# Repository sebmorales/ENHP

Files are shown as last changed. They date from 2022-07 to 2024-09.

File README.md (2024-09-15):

# Networked Hardware- Getting Started

Woo! You got your board on the mail, or maybe we gave it to you in person, now, what is it? What is it for?
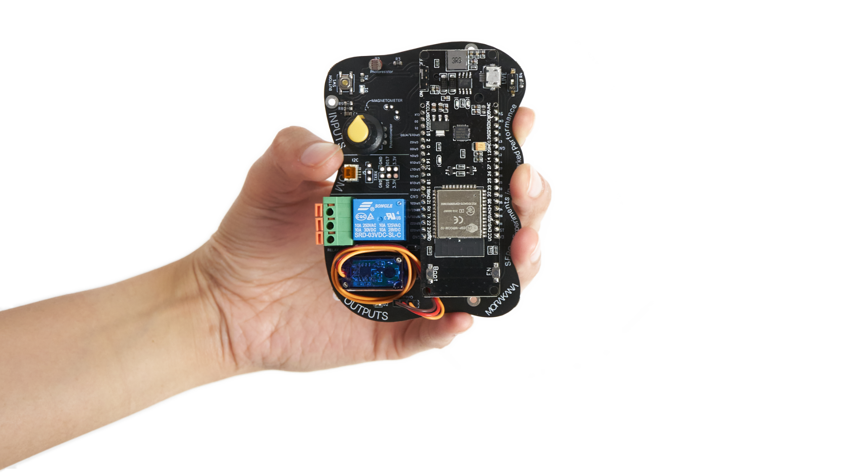
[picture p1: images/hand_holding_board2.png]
Networked Hardware 2.0


This board is based on a ESP32 microcontroller, but it also has some other components to help us get started connecting the digital world and our tangible one. We will go more in depth during class, but for now, here is a quick manual to get you going. 

By default, the board is already pre-programmed, so you don’t have to worry about that. But if you want to make changes, you are more than welcome to do so. We will soon update this same doc to share the code and schematics.

*Note: The board in a bit of an experimental stage and we are still trying to figure things out, so please share any feedback and bugs as you find them :)*

Each board has a unique name (written by hand on the back of the board). Let’s get the boards connected and start sharing light data!

If you go to the webpage [https://hardwaremovement.com](https://hardwaremovement.com) you will see a grid of boxes, each with a name. At the time I took this image, there were only three boards on there, hopefully by now there are many more. As new boards connect, the grid starts getting updated with each boards' last photoresistor reading. 
    
        

This website is only collecting light information, and since other people will likely connect at different times, feel free to come back and see how the collaborative page is changing over time. Feel free to place the board anywhere indoors and see how that impacts the page. 

## Let’s connect!

### How to connect the board to wifi [video]

[https://vimeo.com/725318091](https://vimeo.com/725318091)

### How to connect the board to wifi step by step

1. Turn on the switch on the ESP32 board. 
    1. You will hear a click (that's the relay acting as a small audio cue)
    2. You will see the board blink about 1x a second, this means that the board is attempting to connect to a wifi network. But because you just got the board it will most likely not be able to connect.
        
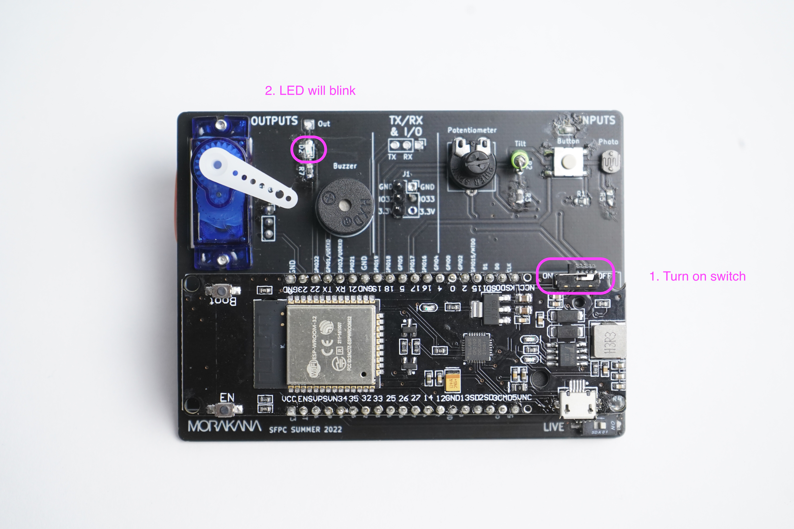
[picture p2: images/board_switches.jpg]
            
2. If after 15 seconds it wasn’t able to connect:
    1. The board will beep again
    2. The LED will start blinking at a faster pace (2x second)
    3. It will then make its own wifi network. You can connect to it to share your wifi credentials. You can do this either though your phone or computer’s wifi settings. 
    
    The name of the network will be *ExperimentHardPerf_[random numbers]*

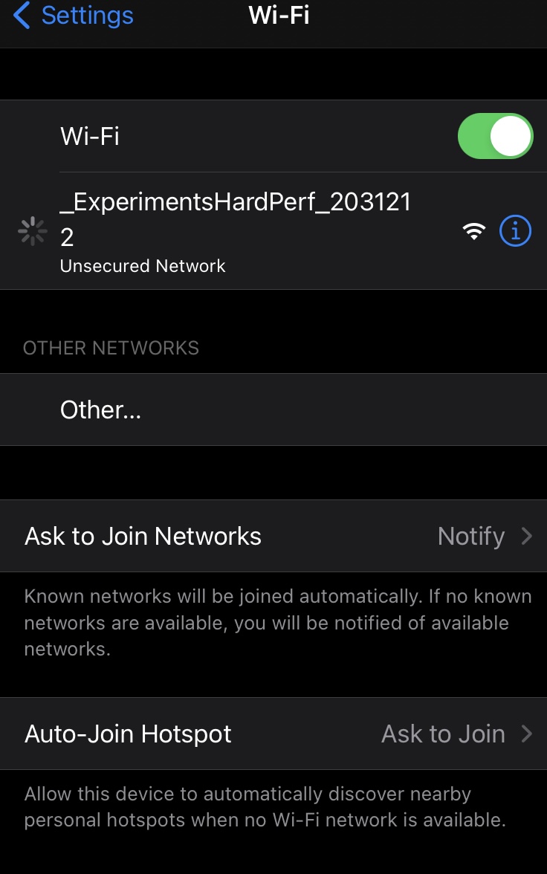
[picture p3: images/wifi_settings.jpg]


1. After 5-10 seconds a login page (captive portal) will show up on your device. 
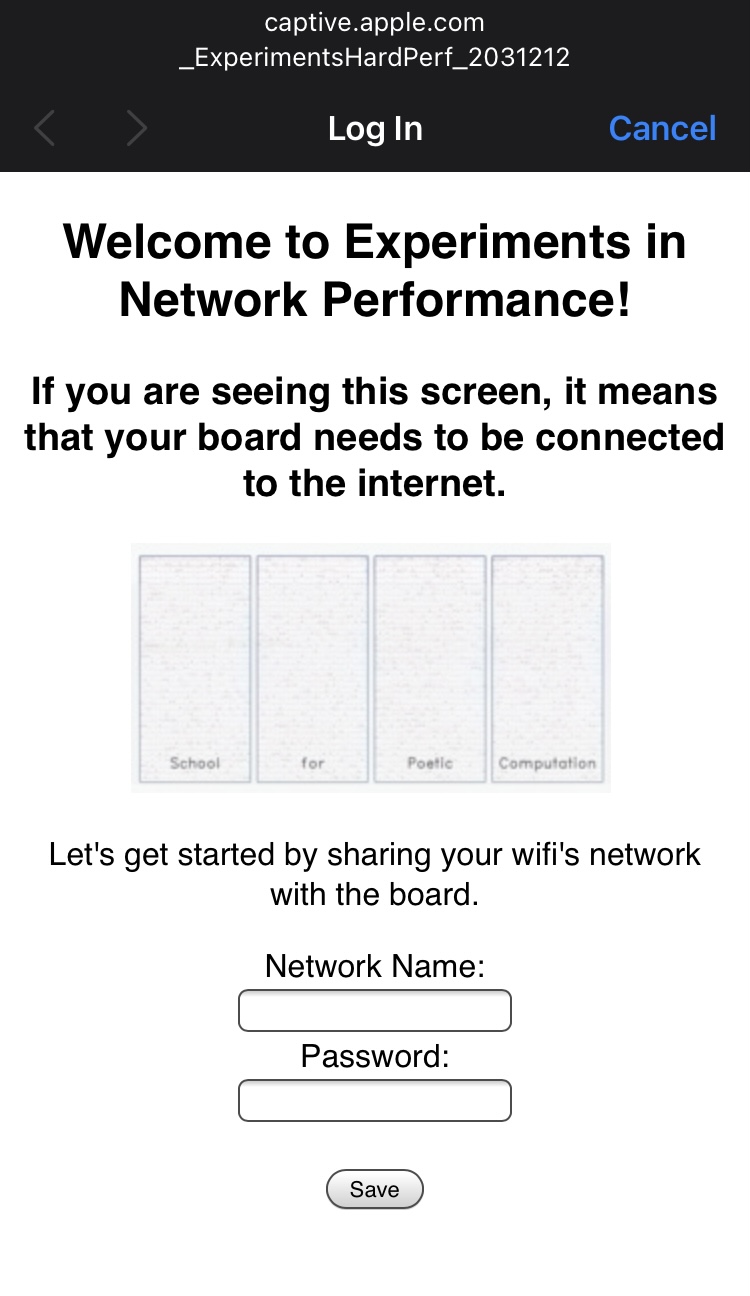
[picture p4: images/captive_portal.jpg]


Note: watch out for upper/lower case

1. Enter your wifi info then click save (Note: watch out for upper/lower case)
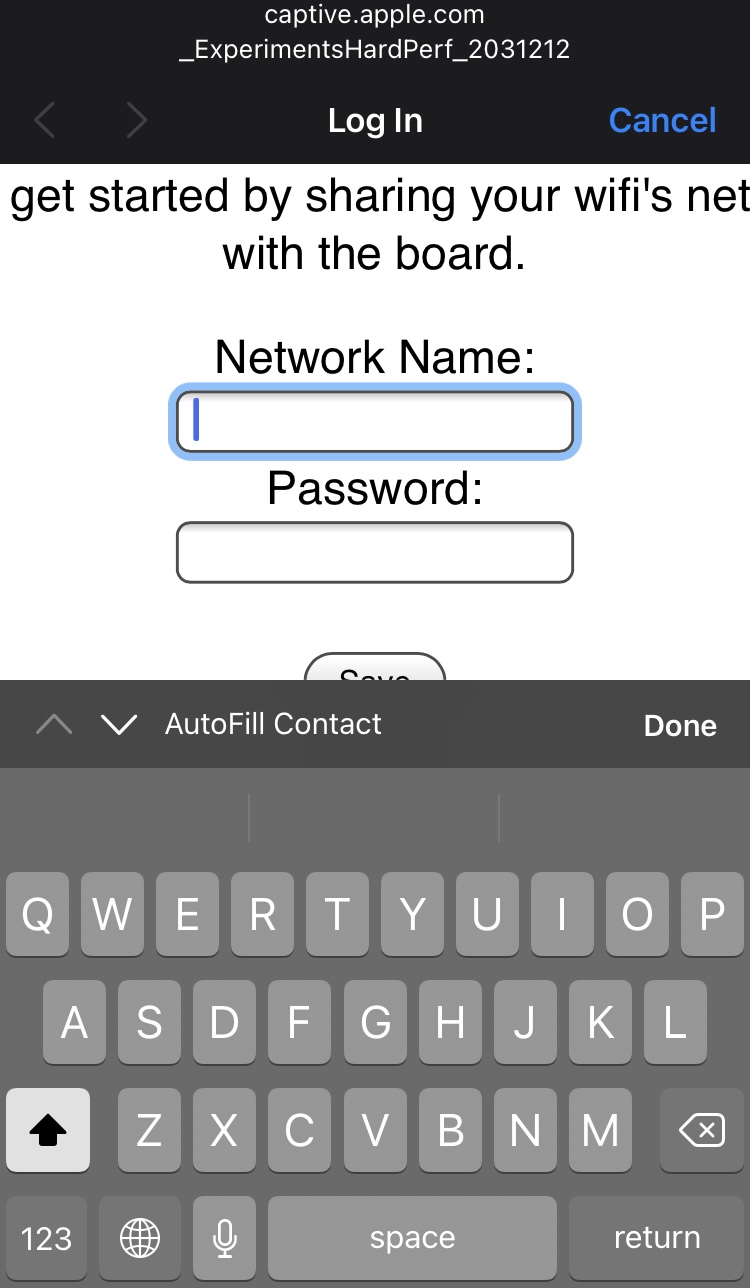
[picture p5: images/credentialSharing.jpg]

Note: watch out for upper/lower case

1. Once you click save, the board will attempt to connect to your network. It will also save your network credentials to it’s internal memory, so you don’t have to add them again (unless you change them). You can now press cancel>use other network, and connect to your regular wifi.

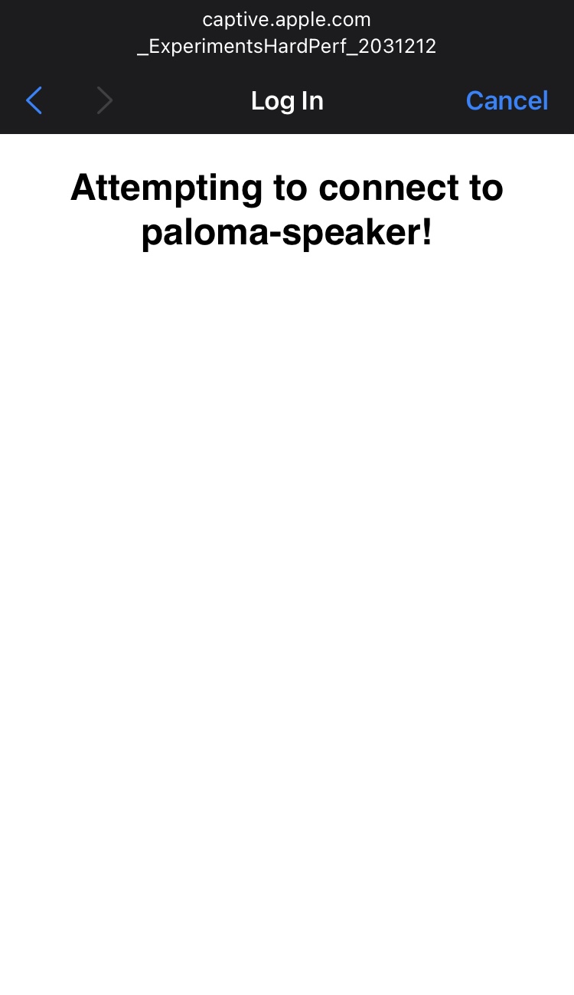
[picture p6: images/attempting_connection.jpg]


1. If the connection is successful, you will see a quick short flashing LED. Then then you can check the [https://hardwaremovement.com](https://hardwaremovement.com)  website again and see it updating live! The board should then go to sleep and automatically wake up every 20 minutes until it rans out of battery in about a day. If you want, you can charge it again or leave it plugged in. 

### Trouble shooting

- I turn it on but nothing happens, no beep, no flashing led.
    
    Most likely, it’s out of battery, try charging it though the micro USB port
    
- I turn the board on, and it beeps, then it beeps again, and again, and again…
    
    This means that the board is constantly restarting, most likely it’s out of battery, try recharging the battery though it’s Micro USB port
    
- I added my wifi credentials but doesn’t nothing happened.
    
    Try restarting the board by turning it off and on again, the board should attempt to connect and if it still is not able, repeat steps 2-6.
    
    Also, in order to save battery, it will only wait for 1minute before going back to sleep. It could be that it’s taking a bit long to add your wifi credentials.
    
- I was able to connect before now it’s asking for my wifi credentials again
    
    The board only has 15 seconds to successfully connect to wifi, after this it will create it’s own network. Sometimes, these 15 seconds are not enough time connect, no need to add you credentials again, you can restart the board and have it try again. 

---

### Additional info: Getting familiar with the board



The board consists of the micocontroller ([ESP32 dev board with a 18650 battery holder](https://wiki.geekworm.com/index.php/WEMOS_ESP32_Board_with_18650_Battery_Holder)) and a series of inputs and outputs:

### **Inputs:**

- **Photoresistor**- This can be used to sense light
- **Magnetometer**- This is the ([MMC5603NJ](mages/MMC5603NJ.pdf)), a 3 axis magnetic + temperature sensor
- **Potentiometer**- This is a knob can be manually turned
- **Button-** This button has a dual function, to send data while the board is awake, and to wake the board when it is sleeping

### **Outputs:**

- **Relay**- Instead of having a buzzer that could only buzz, we upgraded it to a full size relay, it clicks and it switches! We recomend only using it for DC applications, but if you know what you are doing feel free. 
- **An LED output and pin-** this can be used to see changes or to connect to another board or arduino.
- **A Servo-** this can be used to move things in our physical, it can turn about 180°.

### **COM:**
- **I2C**- This uses a STEMMA QT connector, a popular i2C compatible with many Adafruit and Sparkfun modules.
- **RXTX**- These are ready in case you want to connect to another micrcontroller or anything that can communicate though serial. By default the board runs on a 115200 buadrate and only supports 3.3V.
- **GPIO 17 & 18**- By defualt 17 is set to be a digital input (0-1) and 18 is set as an analog out (0-255).
### Power

- The ESP32 board has a switch to turn it on/off
- It can be charged/programmed using a micro USB cable
- We added a small switch to let you decide if the board should stay connected or if it should connect every 20 minutes and then go to sleep. This will dramatically impact how long the board can run on battery.

## Check out [MORAKANA.COM](https://morakana.com/work/networked-hardware2.0) for more details and examples.

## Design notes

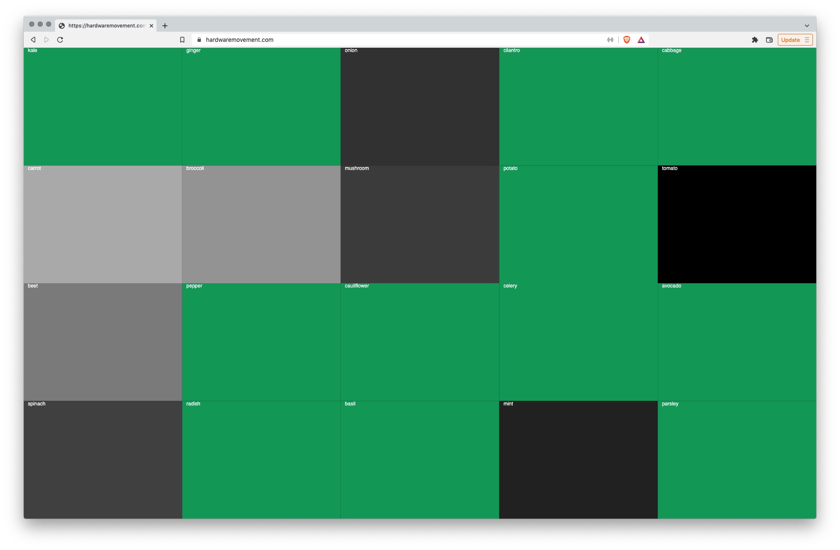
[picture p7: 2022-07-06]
images/hardwaremovement.png

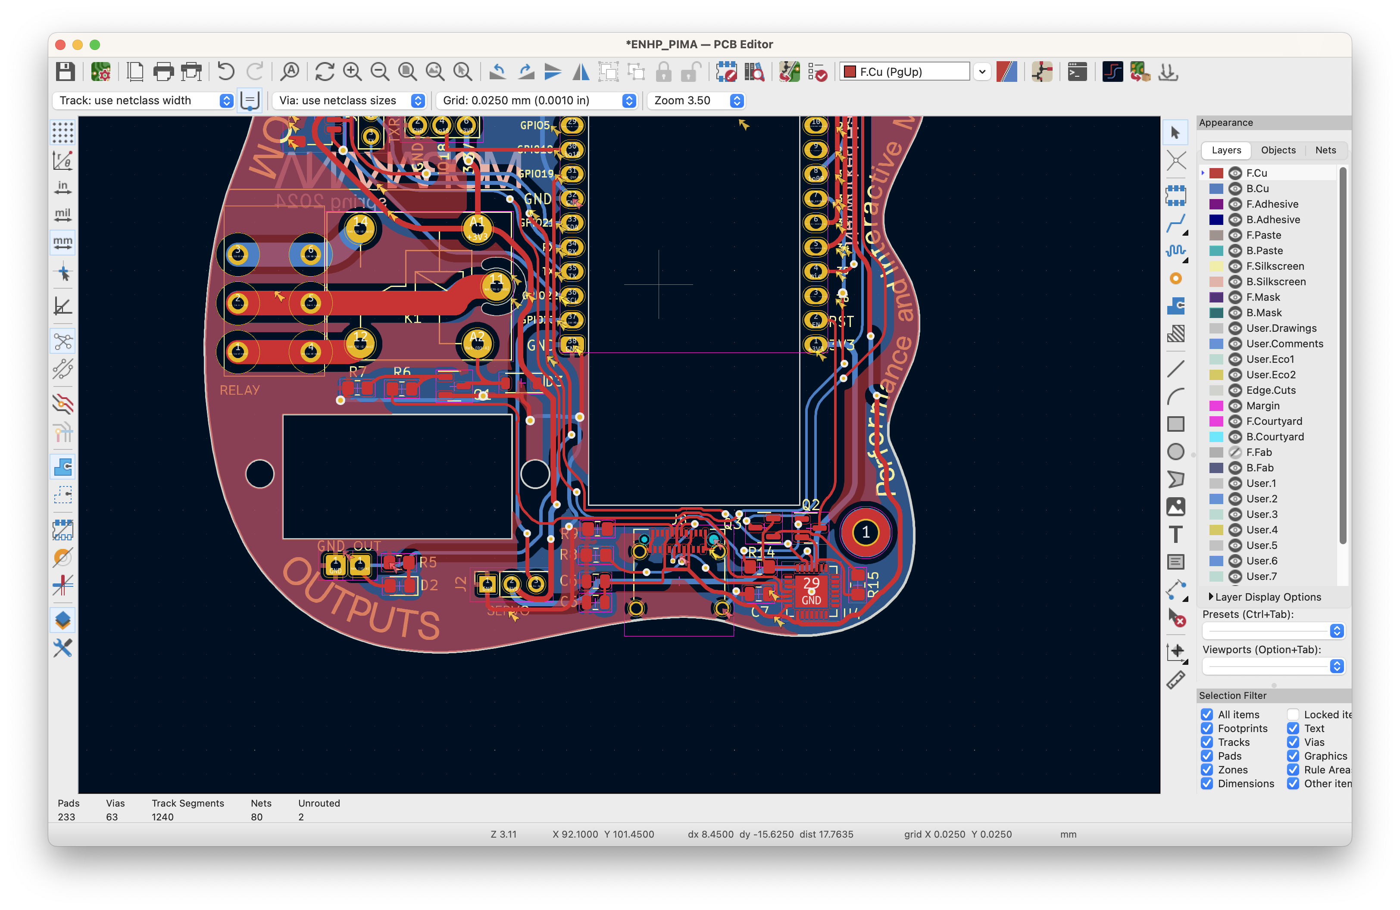
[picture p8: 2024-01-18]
NetworkedHardware_PCB_design/NetworkHardware2.3.png

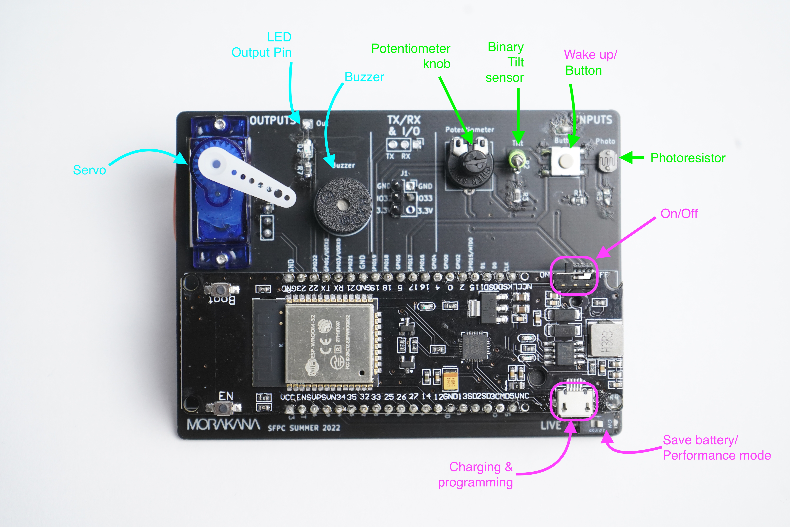
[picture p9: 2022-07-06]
images/boardIO.jpg

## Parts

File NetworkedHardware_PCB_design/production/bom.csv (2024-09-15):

Designator | Footprint | Quantity | Value | LCSC Part #
C1, C4 | 0805 | 2 | 10uF
C2 | 0805 | 1 | 220nF
C3 | 0805 | 1 | 0.1uF
C5 | 0805 | 1 | 1uF
C6, C7 | 0805 | 2 | 100nF
D1, D2 | 0805 | 2 | LED
D3 | D_SOD-123 | 1 | 1N4148W
H1, H4 | MountingHole_2.5mm_Pad_TopBottom | 2 | MountingHole
J1 | PinSocket_2x03_P2.54mm_Vertical | 1 | hookup
J2 | PinSocket_1x03_P2.54mm_Vertical | 1 | SERVO
J3 | PinHeader_1x03_P2.54mm_Vertical | 1 | TXRX
J4 | SolderWire-0.5sqmm_1x01_D0.9mm_OD2.1mm | 1 | OUT0
J5 | JST_SH_SM04B-SRSS-TB_1x04-1MP_P1.00mm_Horizontal | 1 | I2C
J6 | spring_terminal | 1 | ~
J7 | SolderWire-0.5sqmm_1x01_D0.9mm_OD2.1mm | 1 | GND
J8 | USB_C_Receptacle_Amphenol_12401610E4-2A_CircularHoles | 1 | USB_C_Receptacle_USB2.0
K1 | Relay_SPDT_Finder_36.11 | 1 | FINDER-36.11
MIC | S15OT421 | 1 | S15OT421 | C2684419
Q1 | SOT-23 | 1 | MMBT3904
Q2, Q3 | SOT-23 | 2 | BC817
R1 | 0805 | 1 | R220
R10, R11, R14, R15, R3, R7 | 0805 | 6 | 10K
R12, R13 | 0805 | 2 | 2.7K
R2 | R_Axial_DIN0204_L3.6mm_D1.6mm_P2.54mm_Vertical | 1 | Photoresistor
R4 | 0805 | 1 | 1M
R5 | 0805 | 1 | 220
R6 | 0805 | 1 | 1K
R8, R9 | 0805 | 2 | 5.1K
RV5K1 | Potentiometer_Bourns_PTV09A-1_Single_Vertical | 1 | Potentiometer
SW1 | SW_Push_1P1T_NO_CK_KSC7xxJ | 1 | SW_DIP_x01
SW2 | SW_DIP_SPSTx01_Slide_Omron_A6S-110x_W8.9mm_P2.54mm | 1 | SW_DIP_x01
U1 | ESP32-Dev_Batt_18650 | 1 | ESP32-DevKitC
U2 | SOT-23-5 | 1 | MIC5225-3.3YM5 | C512101
U3 | LGA-12_2x2mm_P0.5mm | 1 | LSM303C
U4 | QFN-28-1EP_5x5mm_P0.5mm_EP3.35x3.35mm | 1 | CP2102N-Axx-xQFN28

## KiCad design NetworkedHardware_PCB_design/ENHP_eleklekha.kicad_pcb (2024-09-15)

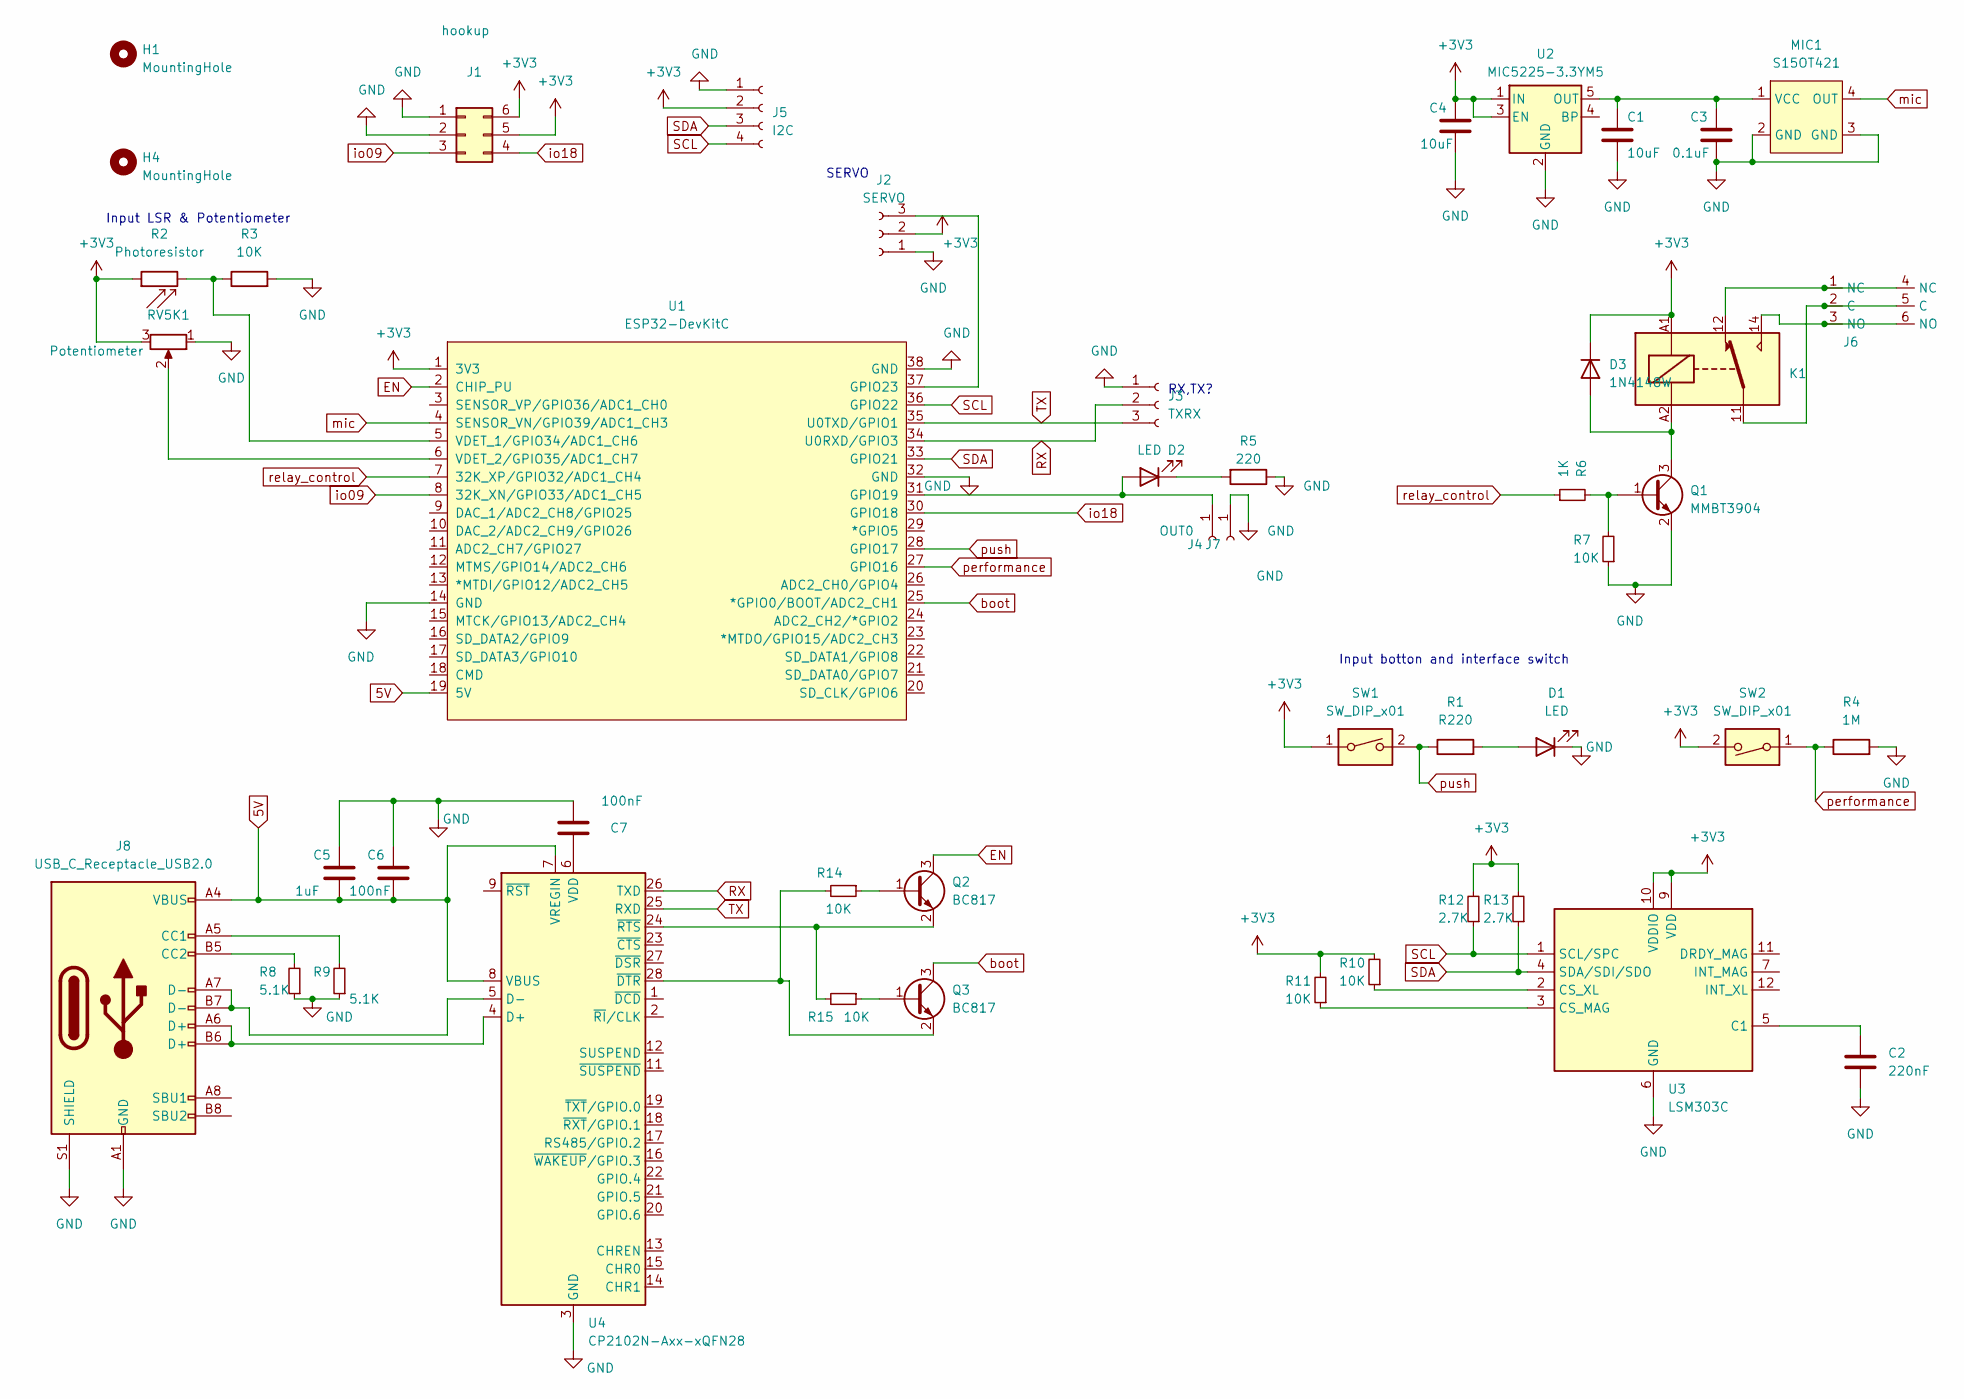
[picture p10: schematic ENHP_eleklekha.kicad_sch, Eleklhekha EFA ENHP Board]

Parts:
C1, C4: 10uF; C_0805_2012Metric
C2: 220nF; C_0805_2012Metric
C3: 0.1uF; C_0805_2012Metric
C5: 1uF; C_0805_2012Metric
C6, C7: 100nF; C_0805_2012Metric
D1, D2: LED; LED_0805_2012Metric_Pad1.15x1.40mm_HandSolder
D3: 1N4148W; D_SOD-123
H1, H4: MountingHole; MountingHole_2.5mm_Pad_TopBottom
J1: hookup; PinSocket_2x03_P2.54mm_Vertical
J2: SERVO; PinSocket_1x03_P2.54mm_Vertical
J3: TXRX; PinHeader_1x03_P2.54mm_Vertical
J4: OUT0; SolderWire-0.5sqmm_1x01_D0.9mm_OD2.1mm
J5: I2C; JST_SH_SM04B-SRSS-TB_1x04-1MP_P1.00mm_Horizontal
J6: spring_terminal
J7: GND; SolderWire-0.5sqmm_1x01_D0.9mm_OD2.1mm
J8: USB_C_Receptacle_USB2.0; USB_C_Receptacle_Amphenol_12401610E4-2A_CircularHoles
K1: FINDER-36.11; Relay_SPDT_Finder_36.11
MIC1: S15OT421; JLC C2684419
Q1: MMBT3904; SOT-23
Q2, Q3: BC817; SOT-23
R1: R220; R_0805_2012Metric_Pad1.20x1.40mm_HandSolder
R2: Photoresistor; R_Axial_DIN0204_L3.6mm_D1.6mm_P2.54mm_Vertical
R3, R7, R10, R11, R14, R15: 10K; R_0805_2012Metric_Pad1.20x1.40mm_HandSolder
R4: 1M; R_0805_2012Metric_Pad1.20x1.40mm_HandSolder
R5: 220; R_0805_2012Metric_Pad1.20x1.40mm_HandSolder
R6: 1K; R_0805_2012Metric_Pad1.20x1.40mm_HandSolder
R8, R9: 5.1K; R_0805_2012Metric_Pad1.20x1.40mm_HandSolder
R12, R13: 2.7K; R_0805_2012Metric_Pad1.20x1.40mm_HandSolder
RV5K1: Potentiometer; Potentiometer_Bourns_PTV09A-1_Single_Vertical
SW1: SW_DIP_x01; SW_Push_1P1T_NO_CK_KSC7xxJ
SW2: SW_DIP_x01; SW_DIP_SPSTx01_Slide_Omron_A6S-110x_W8.9mm_P2.54mm
U1: ESP32-DevKitC; ESP32-Dev_Batt_18650
U2: MIC5225-3.3YM5; SOT-23-5; JLC C512101
U3: LSM303C; LGA-12_2x2mm_P0.5mm
U4: CP2102N-Axx-xQFN28; QFN-28-1EP_5x5mm_P0.5mm_EP3.35x3.35mm

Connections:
5V: C5.2, C6.2, J8.A4 (VBUS), J8.A9 (VBUS), J8.B4 (VBUS), J8.B9 (VBUS), U1.19 (5V), U4.7 (VREGIN), U4.8 (VBUS)
+3V3: C4.2, D3.1 (K), J1.5, J1.6, J2.2, J5.2, K1.A1, R2.1, R10.2, R11.2, R12.2, R13.2, RV5K1.3, SW1.1, SW2.2, U1.1 (3V3), U2.1 (IN), U2.3 (EN), U3.9 (VDD), U3.10 (VDDIO)
EN: Q2.3 (C), U1.2 (CHIP_PU)
GND: C1.1, C2.2, C3.2, C4.1, C5.1, C6.1, C7.1, D1.1 (K), J1.1, J1.2, J2.1, J3.1, J5.1, J7.1, J8.A1 (GND), J8.A12 (GND), J8.B1 (GND), J8.B12 (GND), J8.S1 (SHIELD), MIC1.2 (GND), MIC1.3 (GND), Q1.2 (E), R3.2, R4.2, R5.1, R7.1, R8.1, R9.1, RV5K1.1, U1.14 (GND), U1.32 (GND), U1.38 (GND), U2.2 (GND), U3.6 (GND), U3.8 (GND), U4.3 (GND), U4.29 (GND); also elsewhere on the board
unnamed: D1.2 (A), R1.2
unnamed: D2.2 (A), J4.1, U1.31 (GPIO19)
unnamed: D2.1 (K), R5.2
unnamed: D3.2 (A), K1.A2, Q1.3 (C)
unnamed: J2.3, U1.37 (GPIO23)
unnamed: J6.2 (C), J6.5 (C), K1.11
unnamed: J6.1 (NC), J6.4 (NC), K1.12
unnamed: J6.3 (NO), J6.6 (NO), K1.14
unnamed: J8.A5 (CC1), R9.2
unnamed: J8.B5 (CC2), R8.2
unnamed 14: C1.2, C3.1, MIC1.1 (VCC), U2.5 (OUT); also elsewhere on the board
unnamed: Q1.1 (B), R6.2, R7.2
unnamed: Q2.1 (B), R14.1
unnamed: Q2.2 (E), R15.2, U4.24 (~RTS)
unnamed: Q3.1 (B), R15.1
unnamed: Q3.2 (E), R14.2, U4.28 (~DTR)
unnamed: R2.2, R3.1, U1.5 (VDET_1/GPIO34/ADC1_CH6)
unnamed: RV5K1.2, U1.6 (VDET_2/GPIO35/ADC1_CH7)
unnamed: C2.1, U3.5 (C1)
unnamed: R11.1, U3.3 (CS_MAG)
unnamed: R10.1, U3.2 (CS_XL)
unnamed: J8.A6 (D+), J8.B6 (D+), U4.4 (D+)
unnamed: J8.A7 (D-), J8.B7 (D-), U4.5 (D-)
unnamed: C7.2, U4.6 (VDD)
RX: J3.2, U1.34 (U0RXD/GPIO3), U4.26 (TXD)
SCL: J5.4, R12.1, U1.36 (GPIO22), U3.1 (SCL/SPC)
SDA: J5.3, R13.1, U1.33 (GPIO21), U3.4 (SDA/SDI/SDO)
TX: J3.3, U1.35 (U0TXD/GPIO1), U4.25 (RXD)
boot: Q3.3 (C), U1.25 (*GPIO0/BOOT/ADC2_CH1)
io09: J1.3, U1.8 (32K_XN/GPIO33/ADC1_CH5)
io18: J1.4, U1.30 (GPIO18)
mic: MIC1.4 (OUT), U1.4 (SENSOR_VN/GPIO39/ADC1_CH3); also elsewhere on the board
performance: R4.1, SW2.1, U1.27 (GPIO16)
push: R1.1, SW1.2, U1.28 (GPIO17)
relay_control: R6.1, U1.7 (32K_XP/GPIO32/ADC1_CH4)

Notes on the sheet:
Input LSR & Potentiometer
SERVO
Input botton and interface switch
RX,TX?

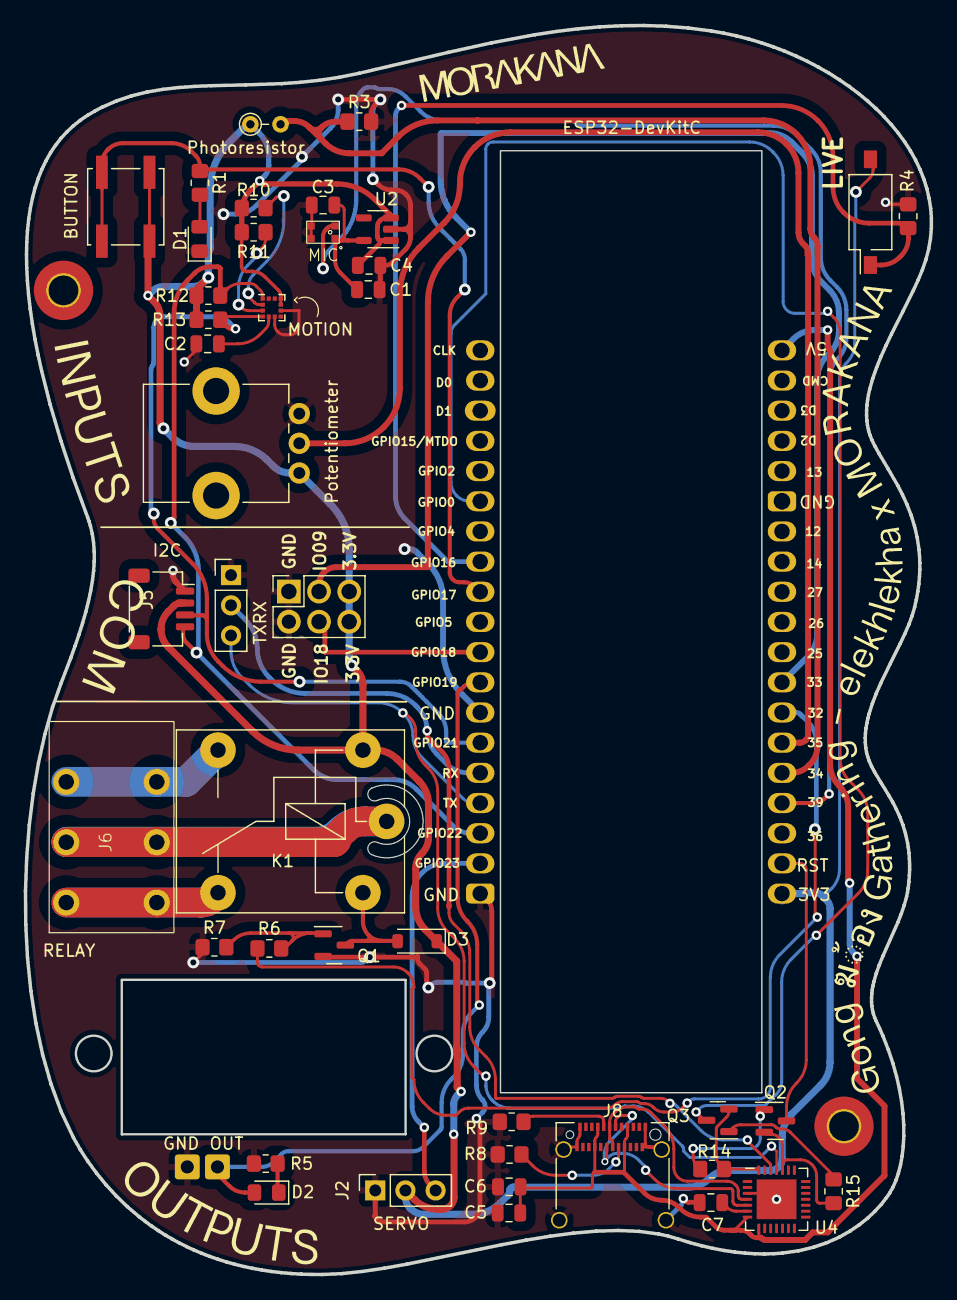
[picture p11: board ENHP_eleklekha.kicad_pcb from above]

Board: 2 copper layers, 76.3 x 105.1 mm, 47 parts (0 on the bottom side), 39 nets.

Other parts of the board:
MIC: S15OT421

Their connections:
GND: MIC.2 (GND), MIC.3 (GND); also elsewhere on the board
unnamed 14: MIC.1 (VCC); also elsewhere on the board
mic: MIC.4 (OUT); also elsewhere on the board

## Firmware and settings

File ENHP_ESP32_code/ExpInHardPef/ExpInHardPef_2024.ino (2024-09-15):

#include "arduino_secrets.h"

//  EXPERIMENTS IN NETWORKED HARDWARE PERFORMANCE
//
//  V2.6
//
//  Elekhlekha 2024
//  MORAKANA
//
// key changes:
// [x] programmable though USB-C
// [x] added secret tab for ssid, pass, and mqtt broker
////////


///////
// USER VARIABLES

//board name
String eeprom_user = "tarared";//carrot24

//network settings (in case you want them pre-loaded)
String net_id=SECRET_ssid;
String net_pass=SECRET_net_pass;

//this is the mqtt broker, you can connect to your own. This is independent from the node-red server.
const char mqtt_broker[]=SECRET_broker_url;
int mqtt_port=1883;

bool debug=false;

////////
// BORD VARIABLES


#include<EEPROM.h>
#include <WiFi.h>
#include <DNSServer.h>
#include <ESP32Servo.h>
#include <ArduinoJson.h>
// #include <MQTT.h>
#include <PubSubClient.h>
#include <Adafruit_Sensor.h>
#include <Adafruit_LIS2MDL.h>
#include <Adafruit_LSM303_Accel.h>

/* Assign a unique ID to this sensor at the same time */
Adafruit_LSM303_Accel_Unified accel = Adafruit_LSM303_Accel_Unified(54321);
Adafruit_LIS2MDL mag = Adafruit_LIS2MDL(12345);

WiFiClient net;
// MQTTClient client;
PubSubClient client(net);

//CAPTIVE PORTAL
const byte DNS_PORT = 53;
IPAddress apIP(8,8,4,4);
// IPAddress apIP(192, 168, 1, 1);
DNSServer dnsServer;
WiFiServer server(80);
String image;
const char netbase[] = "_ExpHardPerf_";


//network credentials
String eeprom_net, eeprom_pass;
boolean connectedSuccess = false;


//OUTPUTS
Servo servo;
// #define servoPin 5
#define servoPin 23
#define out 19
#define relay 32//18

//INPUTS
// #define tilt 34
#define photoresistor 34  
#define potentiometer 35
#define performance  16
#define mic  39
#define button 17
#define battery 36

//pins 17 & 18 can be used as Digital IO & Analog output (no analogRead)
#define io17 33
#define io18 18



boolean out_value = false;
bool ledStatus = false;

// boolean tilt_value = false;
// boolean old_tilt_value = false;
int potentiometer_value = 0;
int old_potentiometer_value = 0;
int photoresistor_value = 0;
int old_photoresistor_value = 0;
boolean button_value;
int io17_value=0;
int old_io17_value=0;
float batt_level=0;
String rx_msg="hi";
bool new_msg=false;
float acc_x;
float acc_y;
float acc_z;
float old_acc=0;

float heading=0;
float old_heading=0;
boolean mag_success=false;
bool acc_success=false;


int mic_readings=200;
int mic_current_reading=0;
int mic_min=1024;
int mic_max=0;
int mic_th= 120;//90
boolean mic_event=false;
boolean old_mic=false;

//time variables
long int timeAwake = 30000; //in battery saving mode, how long (sec) should the board be awake?
long int timeSinceWake = 0;
long int mqttWait = 400; //to avioid sending to many messages a second and saturating/loosing packs
long int lastMessageSent = 0;
long int lastBlink = 0;
int fastBlink = 200;


RTC_DATA_ATTR int bootCount = 0;

#include "soc/soc.h"
#include "soc/rtc_cntl_reg.h"

void setup() {
  WRITE_PERI_REG(RTC_CNTL_BROWN_OUT_REG, 0); //disable brownout detector

  Serial.begin(115200);

  pinMode(out, OUTPUT);
  digitalWrite(out, LOW);   //turn out LED off.
  pinMode(relay, OUTPUT);
  digitalWrite(relay, LOW);
  pinMode(io18, OUTPUT);
  
  pinMode(io17, INPUT_PULLUP);
  pinMode(button, INPUT);
  pinMode(performance, INPUT);
  pinMode(photoresistor, INPUT);
  // pinMode(battery, INPUT);
  
  beep(); //beep every time the board turns on

  loadEEPROM(); //load network credentials stored in memory
  initSleep(); // setup variables to later be able to sleep & wakeup

  //Attempt to connect to wifi, if it doesn't work make your own
  //network for people to connect to share wifi credentials.

  //attempt to connect, if had connected before, it's likley you can connect again, so wait longer before making captive portal
  if (!attemptToConnect() && bootCount < 2) {
    initImage();//load sfpc image
    Serial.println("captive portal");
    runAsServer(); // create captive portal
    timeSinceWake = millis() + 60000; //give some extra time for person to be able to add their credentials
  } else {
    int additionalTry = 0;
    //if you had successfully connected before, try a couple more times
    while (!connectedSuccess && additionalTry < 4) {
      Serial.println(additionalTry);
      additionalTry++;
      attemptToConnect();
    }
    if (!connectedSuccess) {
      initImage();//load sfpc image
      runAsServer(); // create captive portal
      timeSinceWake = millis() + 60000; //give some extra time for person to be able to add their credentials
    }
  }

}

void loop() {
  long int loopTime = millis();
  if (connectedSuccess) {
    client.loop();
    // delay(20);  // <- fixes some issues with WiFi stability
    if (!client.connected()) {
      connect();
    }
  } else {
    portal();
    delay(20);
    if (loopTime - lastBlink > fastBlink) {
      lastBlink = loopTime;
      ledStatus = !ledStatus;
      if (ledStatus) {
        analogWrite(out, 60);
      } else {
        analogWrite(out, 0);
      }
    }
  }


  if (connectedSuccess && loopTime - lastMessageSent > mqttWait) {
    lastMessageSent = loopTime;
    checkInputs(false);//don't force the input broadcast
  }

  // if (connectedSuccess && analogRead(button) < 3600) { //basically pulled down to ground
  if (connectedSuccess && digitalRead(button) ) { //pulled down to ground
    checkInputs(true);
    if(debug){
      Serial.println("button");
    }
    button_value=true;
    delay(100);
    // digitalWrite(out, HIGH);
  }else{
    button_value=false;
  }
  
  if(listenMic()){
    if(debug){
      Serial.println("mic");
    }
    checkInputs(true);
  }

  //after we did everything we have to do, check if we need to sleep (save battery)
  //or keep going.

  if (loopTime - timeSinceWake > timeAwake ) {
    checkPerformanceMode();
    
  }

}


void checkInputs(bool force) {
  boolean change = false;
  
  if(mag_success){
    sensors_event_t event;
    mag.getEvent(&event);
    float Pi=3.14159;
    heading = (atan2(event.magnetic.y,event.magnetic.x) * 180) / Pi;
    if (heading < 0){
      heading = 360 + heading;
    }
    if(abs(old_heading-heading)>5){
      old_heading=heading;
      change=true;
      if(debug){
        Serial.println("heading");
      }   
    }
  }
  
  if(acc_success){
    sensors_event_t event;
    accel.getEvent(&event);
    acc_x=event.acceleration.x;
    acc_y=event.acceleration.y;
    acc_z=event.acceleration.z;
    if(abs(old_acc-abs(acc_x*acc_y*acc_z))>4000){
      old_acc=abs(acc_x*acc_y*acc_z);
      change=true;
      if(debug){
        Serial.println("acc");
      }
    }
  }
  
  photoresistor_value = analogRead(photoresistor);
  // batt_level=round(analogRead(battery)*2*3.3*1.1/4095*100)/100;
  potentiometer_value=analogRead(potentiometer);
  io17_value=digitalRead(io17);

  if (abs(old_potentiometer_value - potentiometer_value) > 60) {// give some margin for noise
    old_potentiometer_value = potentiometer_value;
    change = true;
    if(debug){
      Serial.println("pot");
    }
  }
  if (abs(old_photoresistor_value - photoresistor_value) > 60) {// give some margin for noise
    old_photoresistor_value = photoresistor_value;
    change = true;
    if(debug){
      Serial.println("photo");
    }
  }

  if (old_io17_value!=io17_value) {// give some margin for noise
    old_io17_value = io17_value;
    change = true;
    if(debug){
      Serial.println("io");
    }
  }

  if(Serial.available() > 0){
    rx_msg = Serial.readStringUntil('\n');
    change=true;
    if(debug){
      Serial.println("serial");
    }
  }


  if (change || force) {
    if (connectedSuccess) {
      if(debug){
        Serial.print("change: ");
        Serial.print(change);
        Serial.print(" force: ");
        Serial.println(force);
      }
      mqttSend();
    }
  }
}


void beep() {
  analogWrite(relay, 200);
  delay(20);
  analogWrite(relay, 0);
}

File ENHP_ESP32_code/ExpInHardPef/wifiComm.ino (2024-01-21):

String header;

void runAsServer() {
  delay(100);

  //there is a problem with phones connecting to the same network more than once,
  //the captive portal won't show up, so we need to change the name all the time
  char captiveNetworkName[50] = "";
  unsigned long ran_net = random(10000);

  
  strcpy_P(captiveNetworkName, netbase);//add the first part of the network name

  strcat(captiveNetworkName,eeprom_user.c_str());

  char* ptr = captiveNetworkName + strlen(captiveNetworkName);
  ultoa(ran_net, ptr, 4);
  Serial.println(captiveNetworkName);
  WiFi.softAP(captiveNetworkName);

  WiFi.mode(WIFI_AP);
  // WiFi.softAP("ESP32-DNSServer");
  WiFi.softAPConfig(apIP, apIP, IPAddress(255, 255, 255, 0));

  // i  // if DNSServer is started with "*" for domain name, it will reply with
  // provided IP to all DNS request
  dnsServer.start(DNS_PORT, "*", apIP);
  server.begin();
  delay(1000);
}




//if no network is detected create a captive portal to allow people to provide their network credentials
void portal() {
  dnsServer.processNextRequest();
  WiFiClient client = server.available();   // listen for incoming clients

  boolean newCredentials = false;
  if (client) {
    // If a new client connects,
    Serial.println("New Client.");
    String currentLine = "";                // make a String to hold incoming data from the client
    while (client.connected()) {            // loop while the client's connected
      if (client.available()) {             // if there's bytes to read from the client,
        char c = client.read();             // read a byte, then
        Serial.write(c);                    // print it out the serial monitor
        header += c;
        if (c == '\n') {                    // if the byte is a newline character
          // if the current line is blank, you got two newline characters in a row.
          // that's the end of the client HTTP request, so send a response:
          if (currentLine.length() == 0) {
            // HTTP headers always start with a response code (e.g. HTTP/1.1 200 OK)
            // and a content-type so the client knows what's coming, then a blank line:
            client.println("HTTP/1.1 200 OK");
            client.println("Content-type:text/html");
            client.println("Connection: close");
            client.println();

            if (header.indexOf("/network/") >= 0) {
              Serial.println(header);
              String network = getValue(header, '/', 2);
              String password = getValue(header, '/', 3);
              network.replace("%20"," ");//if the username or password have spaces, make sure these are passed properly
              password.replace("%20"," ");
              //              String user = getValue(header, '/', 4);

              //save data to EEPROM
              //start by cleaning the EEPROM
              for (int i = 0 ; i < eepromSize  ; i++) {
                EEPROM.write(i, 0);
              }
             
              EEPROM.writeString(eepromAddr1, network);
              EEPROM.writeString(eepromAddr2, password);
//              EEPROM.writeString(eepromAddr3, eeprom_user);
              EEPROM.commit();
              newCredentials = true; //try out new credentials
              delay(500);

              //attempting to connect:
              client.println("<!DOCTYPE html><html>");
              client.println("<head><meta name=\"viewport\" content=\"width=device-width, initial-scale=1\">");
              client.println("<link rel=\"icon\" href=\"data:,\">");
              client.println("<style>html { font-family: Helvetica; display: inline-block; margin: 0px auto; text-align: center;}");
              client.println("</style></head>");
              client.println("<body><h2>Attempting to connect to " + network + "!</h2>");
              client.println("<body><p>You may now close this window (Join other network)!</p>");
              client.println("</body></html>");
              client.println();//end response with blank line

            }
            else {
              // Display the HTML web page
              client.println("<!DOCTYPE html><html>");
              client.println("<head><meta name=\"viewport\" content=\"width=device-width, initial-scale=1\">");
              client.println("<link rel=\"icon\" href=\"data:,\">");
              client.println("<style>html { font-family: Helvetica; display: inline-block; margin: 0px auto; text-align: center;}");
              client.println("</style></head>");

              // Web Page Heading
              client.println("<body><h2>Welcome to Experiments in Network Performance!</h2>");
              client.println("<body><h3>If you are seeing this screen, it means that your board needs to be connected to the internet.</h3>");
              client.println(image);

              client.println("<br>");
              client.println("<p>Let's get started by sharing your wifi's network with the board. </p>" );
              client.println("<label for=\"fname\">Network Name:</label><br>");
              client.println("<input type=\"text\" id=\"netName\"><br>");
              client.println("<label for=\"lname\">Password:</label><br>");
              client.println("<input type=\"text\" id=\"netPass\"><br><br>");
              //              client.println("<p>Give this board a unique name, we will use this name later to connect to it on the interent.</p>");
              //              client.println("<label for=\"fname\">Board name:</label><br>");
              //              client.println("<input type=\"text\" id=\"userName\" ><br>");
              client.println("<button onclick=myFunction()>Save</>");

              client.println("<script>");
              client.println("function myFunction(){");
              client.println("var name = document.getElementById(\"netName\").value");
              client.println("var pass = document.getElementById(\"netPass\").value");
              //              client.println("var user = document.getElementById(\"userName\").value");
              //              client.println("var path = \"/network/\"+name+\"/\"+pass+\"/\"+user+\"/\"");
              client.println("var path = \"/network/\"+name+\"/\"+pass+\"/\"");

              client.println("window.location.href=path");
              client.println("}");
              client.println("</script>");

              client.println("</body></html>");
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

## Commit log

2022-07-09 Fixed bugs detected in class
    Fixed:
    * Added board name to network name
    * Fixed MQTT Connection ID
    * Fixed error sharing network names with spaces in them " ".
    [mqtt.ino, wifiComm.ino]
2023-06-19 MMC5603NJ 3 axis low cost magnetic sensor
    added datasheet
2023-06-19 Networked Hardware2.0
    Hand holding board
2023-06-19 Updated to 2023 version
    Added magnetic sensor, relay, and improved general flow.
2023-06-24 KiCad files
    Uploaded design files for circuit board.
    [esp32_R3.kicad_pcb, esp32_R3.kicad_sch]
2023-06-24 added kicad image
2024-01-06 Updated for LSM303
    I replaced the magnetometer to the LSM303 which is better and more accessible. Also added a mic.
    [ExpInHardPef_2023_Performance.ino, eeprom.ino, mag_acc.ino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]
2024-01-18 Added production files
    this new 2.3 version includes USB-C charging and programming, this in hopes to relieve the strain on the micro usb port on the esp32 board
    [ENHP_PIMA.kicad_pcb, ENHP_PIMA.kicad_sch, NH2.4_JLC_BOM.xls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]
2024-01-18 Removed old versions
    [esp32_R3.kicad_pcb, esp32_R3.kicad_sch]
2024-01-21 updated code for easier user changes
    Made variables like network, mqtt broker, and debugging more accessible
    [ExpInHardPef_2023_Performance.ino, eeprom.ino, mag_acc.ino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]
2024-09-15 updated code for elekhlekha
    Adjusted mic sensitivity
    moved ssid and pass to secrets tab
    [ENHP_PIMA.kicad_pcb, ENHP_PIMA.kicad_sch, NH2.4_JLC_BOM.xls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]
2024-09-15 USB C serial update
    updated PCB design to fix USB C Serial
    [ENHP_PIMA.kicad_pcb, ENHP_PIMA.kicad_sch, ENHP_eleklekha.kicad_pcb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]
